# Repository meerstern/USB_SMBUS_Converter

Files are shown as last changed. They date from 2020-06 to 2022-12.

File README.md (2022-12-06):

# USB_SMBUS_Converter
USB SMBus converter with CP2112

## 概要 
  * [CP2112][1]を使用したUSB-SMBUS/I2C変換基板です  
  * [Simplicity Studio][2]を使用してVIDやPID等のパラメータを設定変更できます  
  * [USBオーディオブリッジ CP2615][3]のパラメータ書き換えに最適です  
  * サイズ30mm x20mm 

## 注意
 * [Simplicity Studio][2]を使用したパラメータ書き換えはOne-Time Programmable ROMで1回のみです  
 * 2回以上の書き換えはできませんので書き換えの際は間違えないように注意してください  
 * 出荷時の初期値は下記のパラメータ設定となっており、1回のみ別の値に書き換えできます  
 
|  Name  |  Default Value  |
| ---- | ---- |
|  VID  |  10C4h  |
|  PID  |  EA90h  |
|  Power Descriptor1  |  80h (Bus-Powered)  |
|  Power Descriptor2  |  32h (100 mA)  |
|  Release Number  |  0100h (Release Version 01.00)  |
|  Manufacturer String  |  Silicon Laboratories  |
|  Product Description String  |  CP2112 HID USB-to-SMBus Bridge  |
|  Serial String  |  Unique 8-character ASCII string |  

## 販売サイト
  * [スイッチサイエンス][4]
 
[1]: https://jp.silabs.com/interface/usb-bridges/classic/device.cp2112
[2]: https://jp.silabs.com/products/development-tools/software/simplicity-studio
[3]: https://github.com/meerstern/USB_PDM_Converter
[4]: https://www.switch-science.com/products/6489

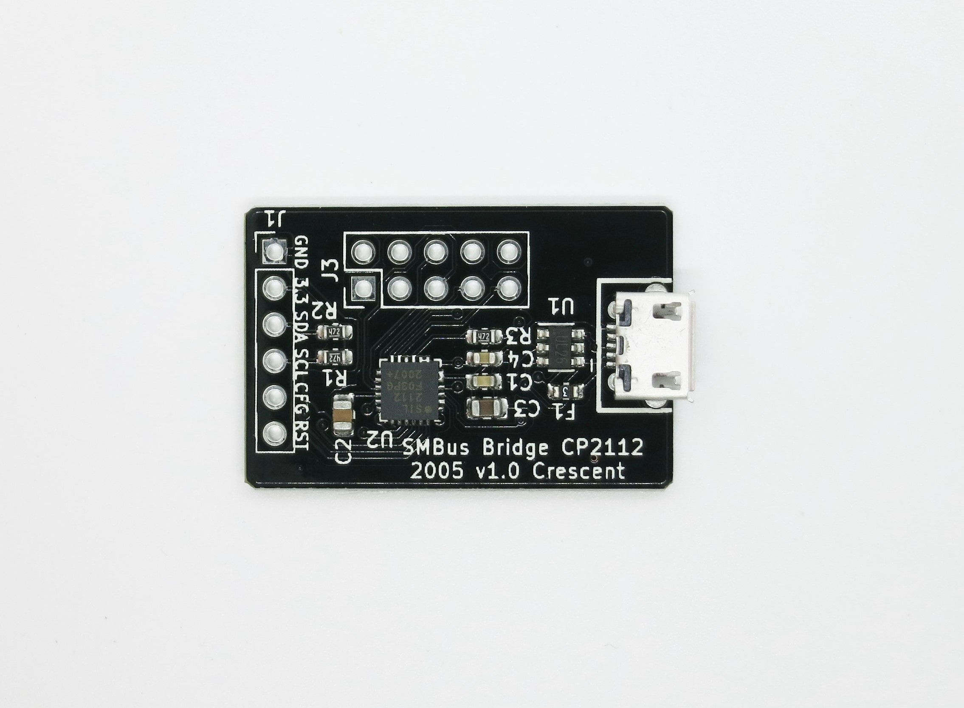
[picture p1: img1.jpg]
   
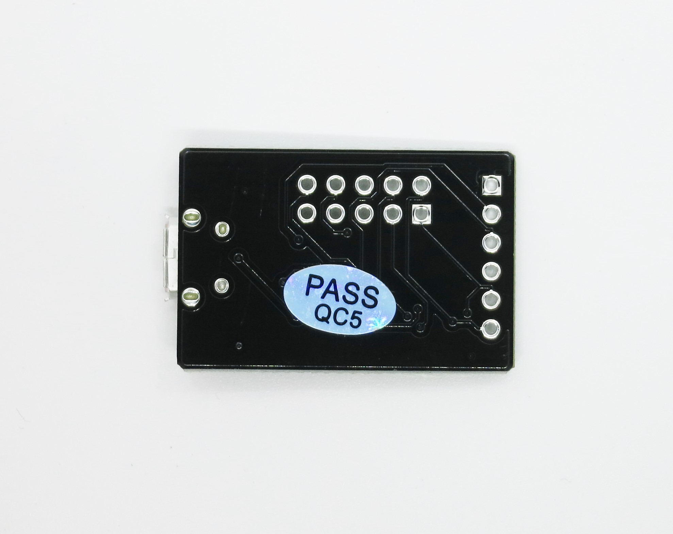
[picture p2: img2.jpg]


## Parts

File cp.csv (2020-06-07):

ID | 参照記号 | パッケージ | 数 | 名称 | Supplier and ref
1 | U2 | QFN-24-1EP_4x4mm_P0.5mm_EP2.6x2.6mm | 1 | CP2112
2 | R3,R2,R1 | R_0603_1608Metric | 3 | 4.7k
3 | J3 | PinHeader_2x05_P2.54mm_Vertical | 1 | Conn_02x05_Odd_Even
4 | C2,C3 | C_0805_2012Metric | 2 | 4.7u
5 | U1 | SOT-23-6 | 1 | USBLC6-2
6 | J2 | CONN-10118194-0001LF-FCI | 1 | USB_B_Micro
7 | J1 | PinHeader_1x06_P2.54mm_Vertical | 1 | Cfg
8 | F1 | Fuse_0603_1608Metric | 1 | Fuse
9 | C4 | C_0603_1608Metric | 1 | 1u
10 | C1 | C_0603_1608Metric | 1 | 0.1u

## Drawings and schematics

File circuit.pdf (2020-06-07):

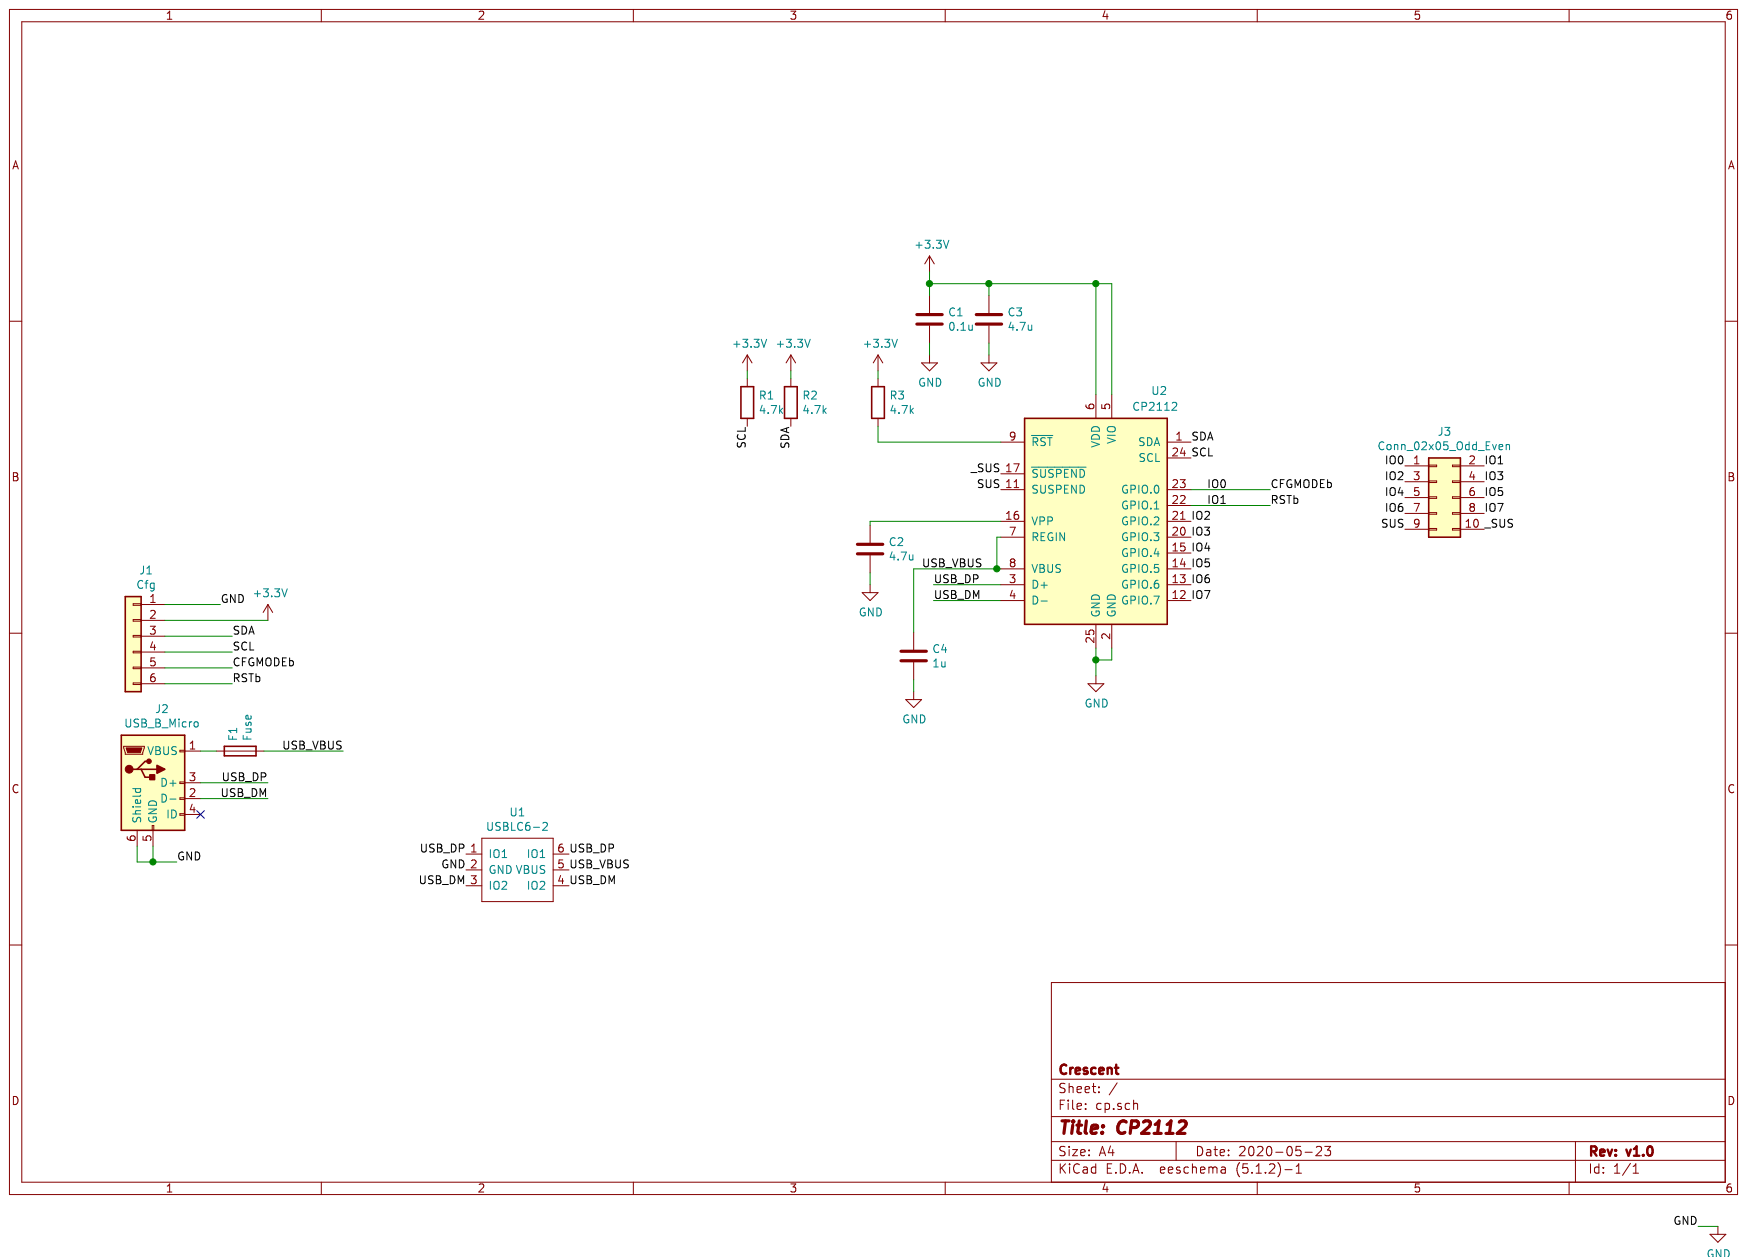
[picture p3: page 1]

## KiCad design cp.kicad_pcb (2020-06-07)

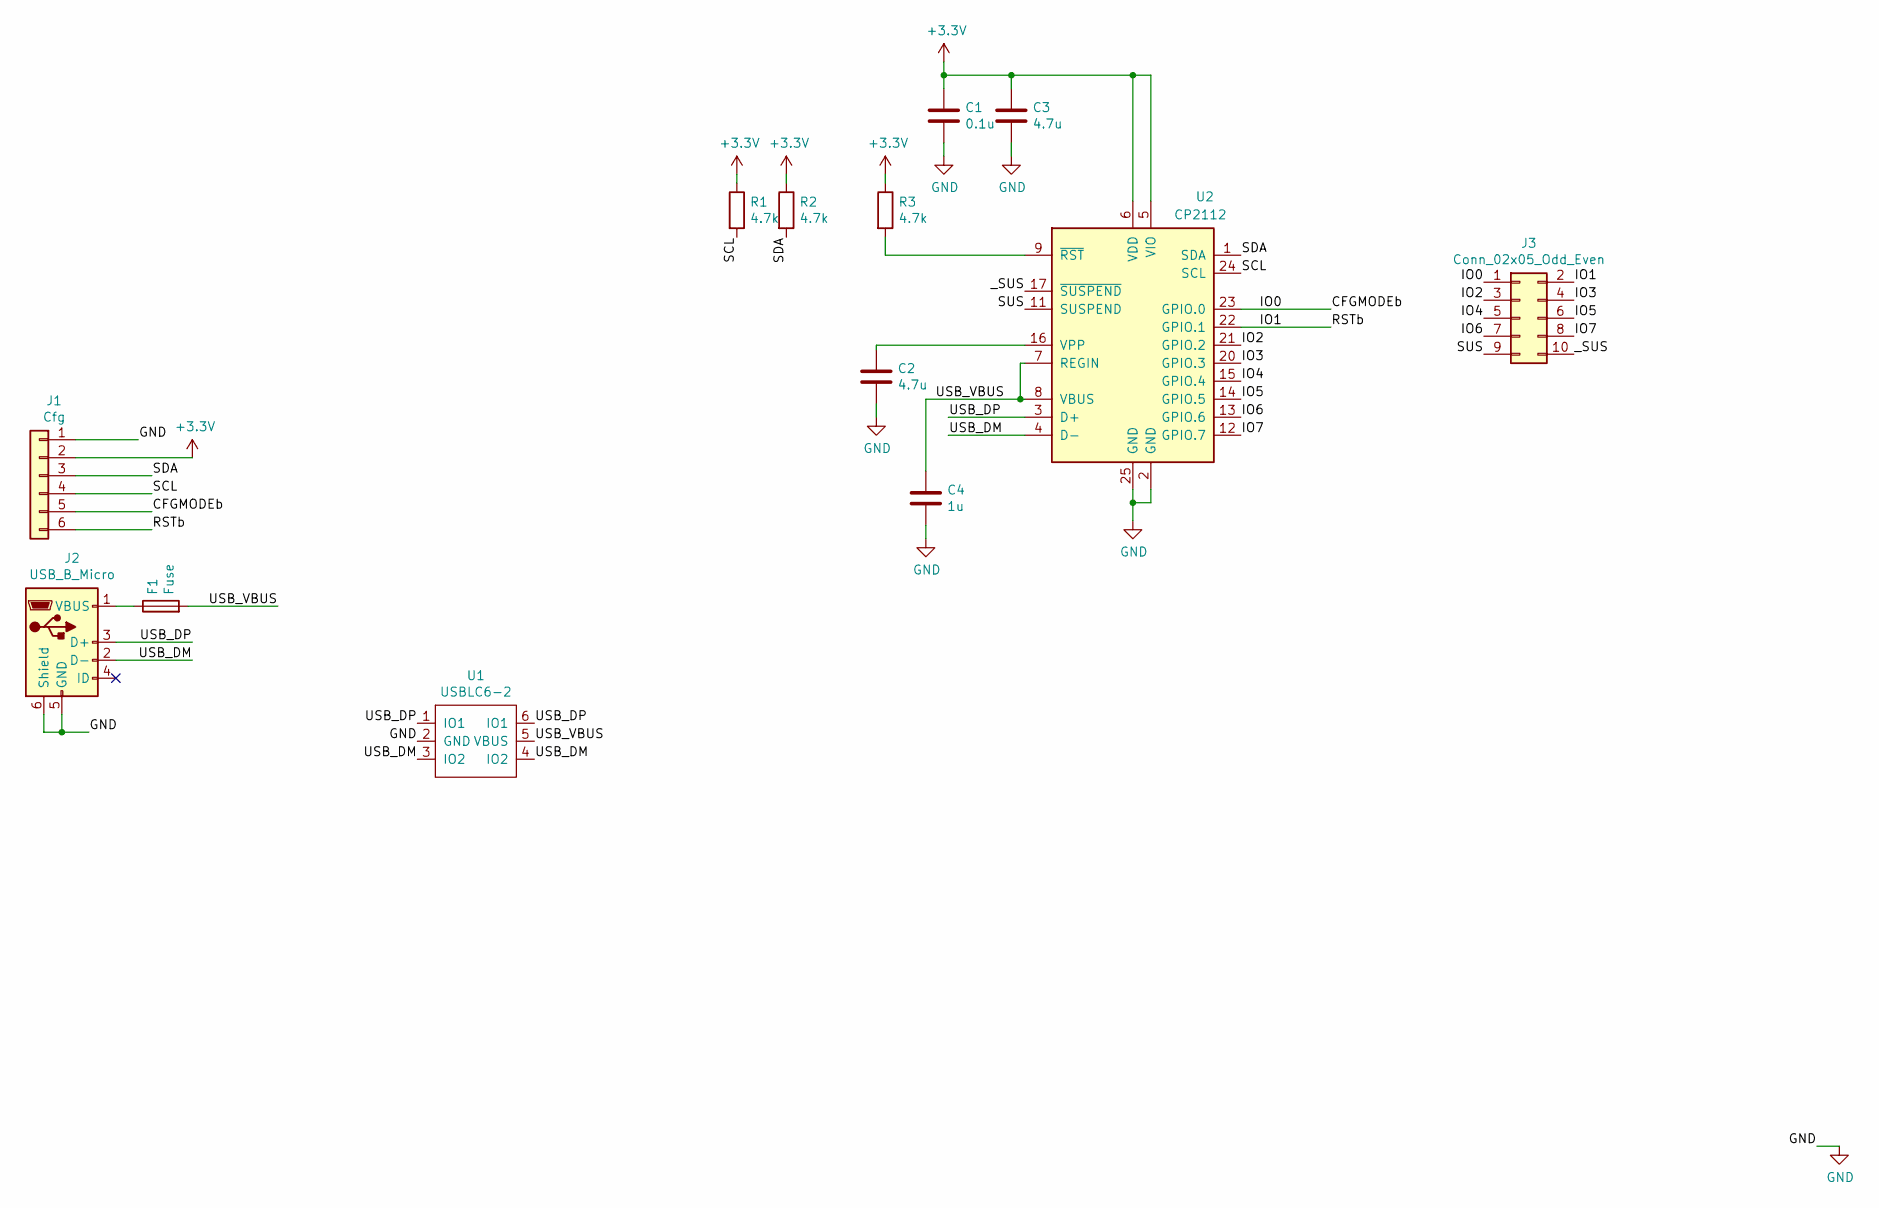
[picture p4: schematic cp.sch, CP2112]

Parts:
C1: 0.1u; C_0603_1608Metric
C2, C3: 4.7u; C_0805_2012Metric
C4: 1u; C_0603_1608Metric
F1: Fuse; Fuse_0603_1608Metric
J1: Cfg; PinHeader_1x06_P2.54mm_Vertical
J2: USB_B_Micro; CONN-10118194-0001LF-FCI
J3: Conn_02x05_Odd_Even; PinHeader_2x05_P2.54mm_Vertical
R1, R2, R3: 4.7k; R_0603_1608Metric
U1: USBLC6-2; SOT-23-6
U2: CP2112; QFN-24-1EP_4x4mm_P0.5mm_EP2.6x2.6mm

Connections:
+3V3: C1.1, C3.1, J1.2, R1.1, R2.1, R3.1, U2.5 (VIO), U2.6 (VDD)
/CFGMODEb: J1.5, J3.1, U2.23 (GPIO.0)
/IO1: J1.6, J3.2, U2.22 (GPIO.1)
/IO2: J3.3, U2.21 (GPIO.2)
/IO3: J3.4, U2.20 (GPIO.3)
/IO4: J3.5, U2.15 (GPIO.4)
/IO5: J3.6, U2.14 (GPIO.5)
/IO6: J3.7, U2.13 (GPIO.6)
/IO7: J3.8, U2.12 (GPIO.7)
/SCL: J1.4, R1.2, U2.24 (SCL)
/SDA: J1.3, R2.2, U2.1 (SDA)
/SUS: J3.9, U2.11 (SUSPEND)
/USB_DM: J2.2 (D-), U1.3 (IO2), U1.4 (IO2), U2.4 (D-)
/USB_DP: J2.3 (D+), U1.1 (IO1), U1.6 (IO1), U2.3 (D+)
/USB_VBUS: C4.1, F1.2, U1.5 (VBUS), U2.7 (REGIN), U2.8 (VBUS)
/_SUS: J3.10, U2.17 (~SUSPEND)
GND: C1.2, C2.2, C3.2, C4.2, J1.1, J2.5 (GND), J2.6 (Shield), U1.2 (GND), U2.2 (GND), U2.25 (GND)
unnamed: C2.1, U2.16 (VPP)
unnamed: F1.1, J2.1 (VBUS)
unnamed: R3.2, U2.9 (~RST)

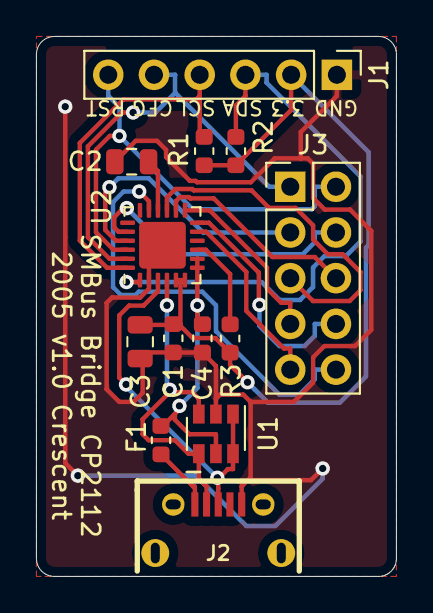
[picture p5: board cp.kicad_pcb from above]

Board: 2 copper layers, 20.0 x 30.0 mm, 13 parts (0 on the bottom side), 20 nets.
